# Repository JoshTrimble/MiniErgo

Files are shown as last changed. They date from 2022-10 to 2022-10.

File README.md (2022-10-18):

This design was inspired by the Gboards' GergoPlex. I wanted to take the base design and tweak it to be a smaller form factor, while maintaining the layout as much as possible. This board is driven by 2 Xiao Seeed Studio RP2040s and includes hot swappable sockets for Kailh Choc switches. The PCB is designed yp be double sided with the left side having the micro control placed upside down via standoffs.

One other thing to note; Because of the minimal footprint achieved, there might be a very slight overhang of the outer hot swap socket solder points and the edge of the board depending on the hot swap sockets used. There should be plenty of room for contact of the PCB tracks to the socket, and the excess can be sanded down to be flush with the PCB if desired. From my testing, you can't even notice. This design might be changed in future versions of the board. (P.S. Know that sanding PCBs can be hazardous. Please take procautions if you choose to sand anything attached to the board)

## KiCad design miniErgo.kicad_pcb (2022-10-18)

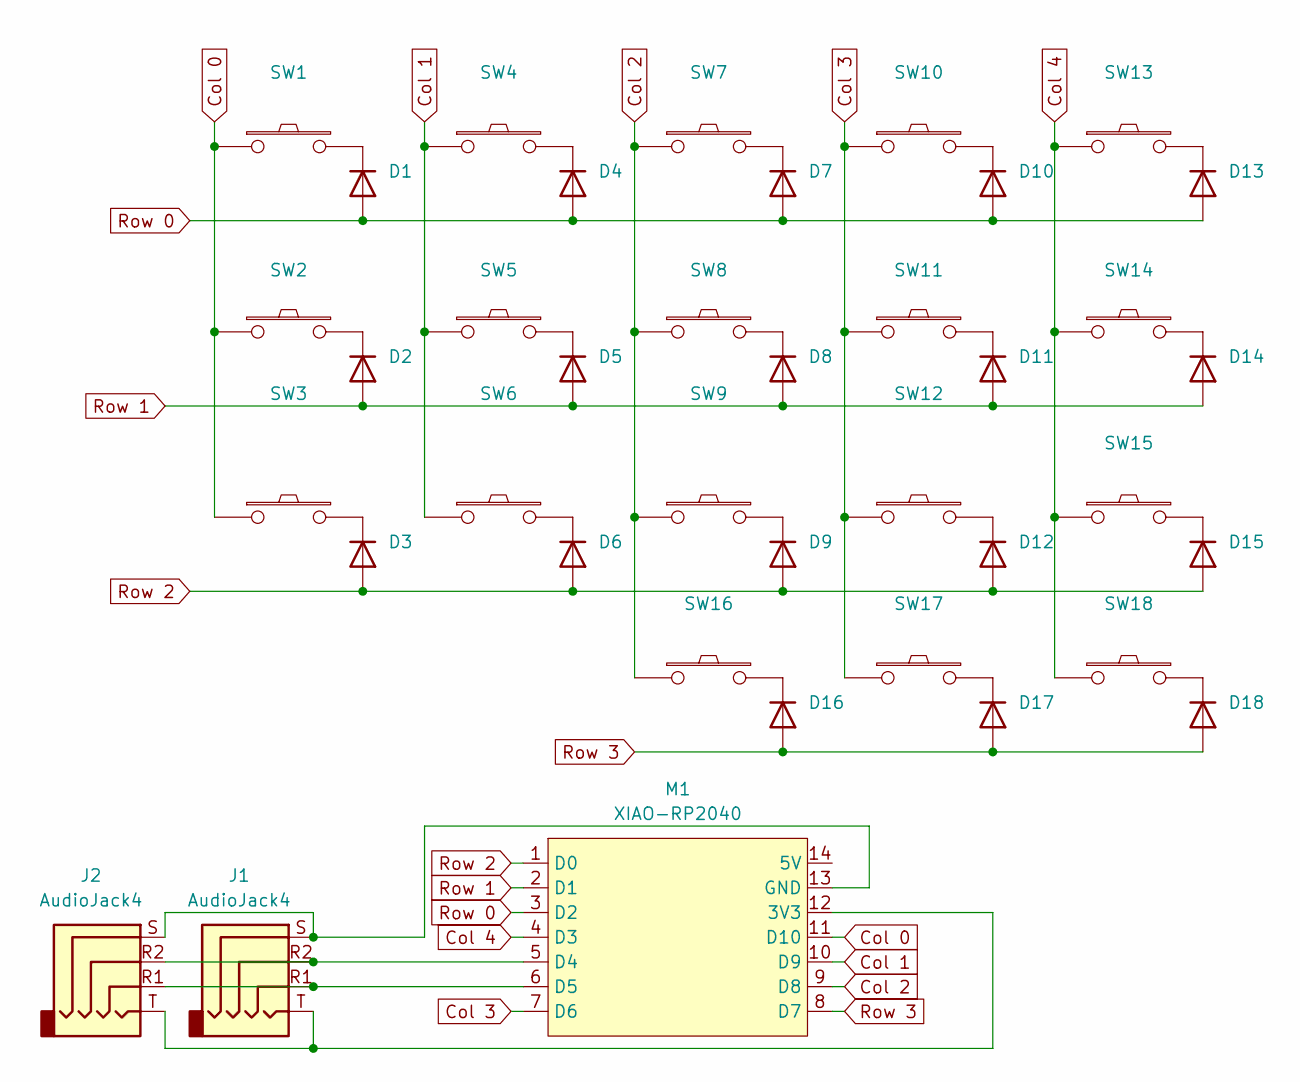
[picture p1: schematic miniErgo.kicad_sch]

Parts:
D1, D2, D3, D4, D5, D6, D7, D8, D9, D10, D11, D12, D13, D14, D15, D16, D17, D18: SOD-123F Double Sided
J1, J2: AudioJack4; TRRS-PJ-320A
M1: XIAO-RP2040
SW1, SW2, SW3, SW4, SW5, SW6, SW7, SW8, SW9, SW10, SW11, SW12, SW13, SW14, SW15, SW16, SW17, SW18: Kailh Choch HS Double Sided

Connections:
Col 0: M1.11 (D10), SW1.1, SW2.1, SW3.1
Col 1: M1.10 (D9), SW4.1, SW5.1, SW6.1
Col 2: M1.9 (D8), SW7.1, SW8.1, SW9.1, SW16.1
Col 3: M1.7 (D6), SW10.1, SW11.1, SW12.1, SW17.1
Col 4: M1.4 (D3), SW13.1, SW14.1, SW15.1, SW18.1
unnamed: D1.1 (K), SW1.2
unnamed: D2.1 (K), SW2.2
unnamed: D3.1 (K), SW3.2
unnamed: D4.1 (K), SW4.2
unnamed: D5.1 (K), SW5.2
unnamed: D6.1 (K), SW6.2
unnamed: D7.1 (K), SW7.2
unnamed: D8.1 (K), SW8.2
unnamed: D9.1 (K), SW9.2
unnamed: D10.1 (K), SW10.2
unnamed: D11.1 (K), SW11.2
unnamed: D12.1 (K), SW12.2
unnamed: D13.1 (K), SW13.2
unnamed: D14.1 (K), SW14.2
unnamed: D15.1 (K), SW15.2
unnamed: D16.1 (K), SW16.2
unnamed: D17.1 (K), SW17.2
unnamed: D18.1 (K), SW18.2
unnamed: J1.R1, J2.R1, M1.6 (D5)
unnamed: J1.R2, J2.R2, M1.5 (D4)
unnamed: J1.S, J2.S, M1.13 (GND)
unnamed: J1.T, J2.T, M1.12 (3V3)
Row 0: D1.2 (A), D4.2 (A), D7.2 (A), D10.2 (A), D13.2 (A), M1.3 (D2)
Row 1: D2.2 (A), D5.2 (A), D8.2 (A), D11.2 (A), D14.2 (A), M1.2 (D1)
Row 2: D3.2 (A), D6.2 (A), D9.2 (A), D12.2 (A), D15.2 (A), M1.1 (D0)
Row 3: D16.2 (A), D17.2 (A), D18.2 (A), M1.8 (D7)

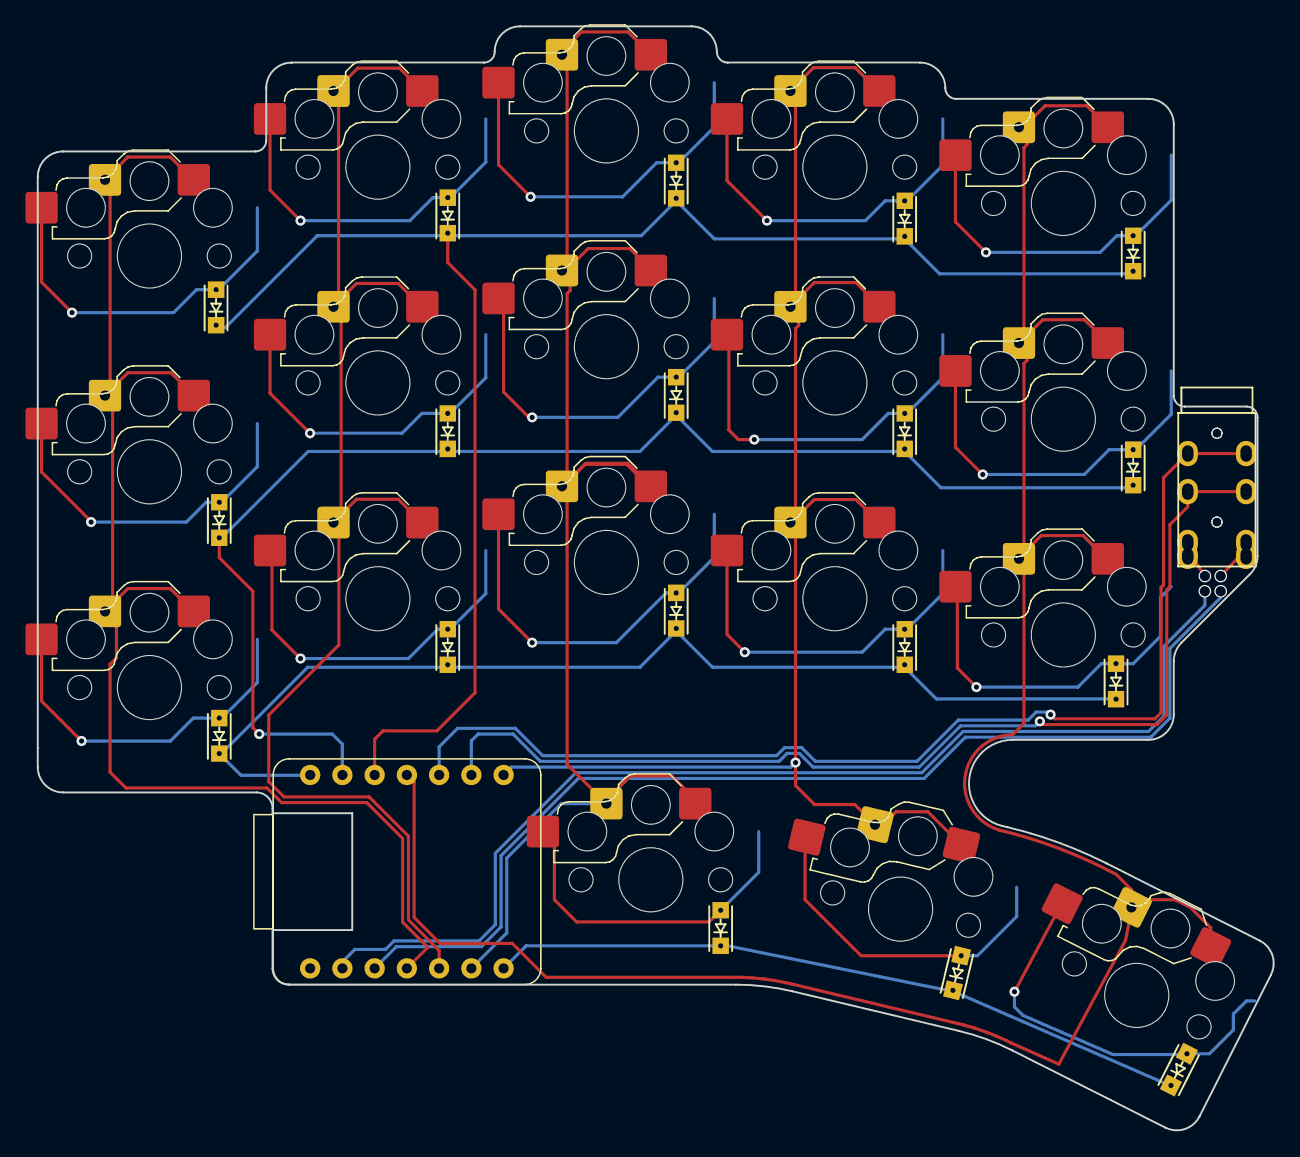
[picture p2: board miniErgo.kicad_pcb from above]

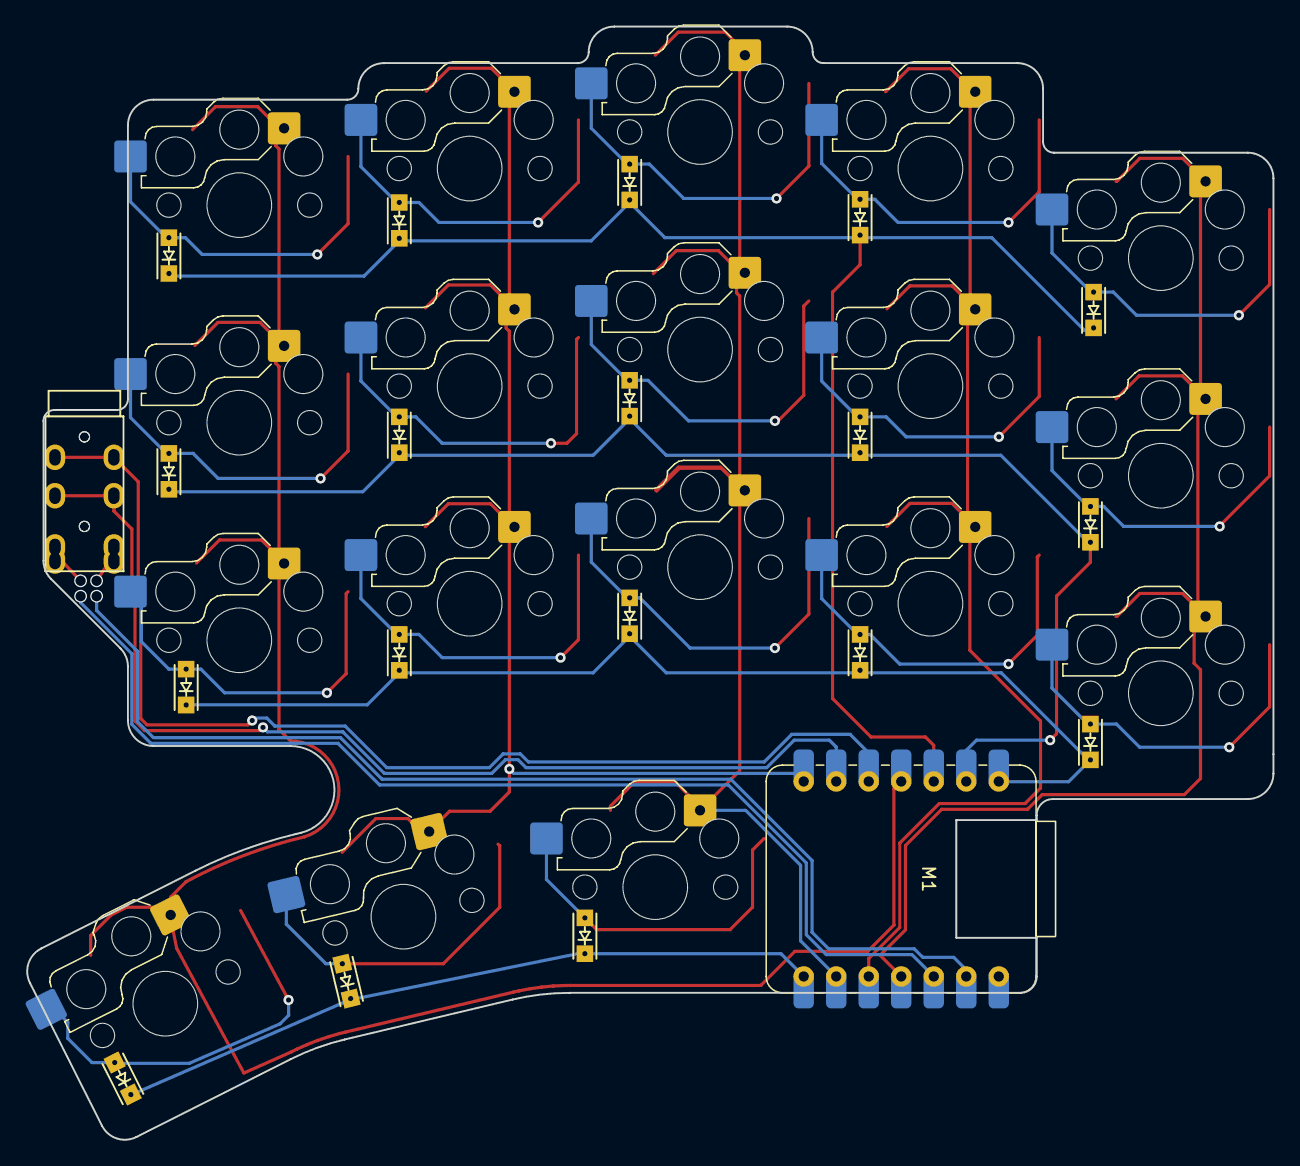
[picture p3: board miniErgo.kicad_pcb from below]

Board: 2 copper layers, 97.4 x 87.0 mm, 39 parts (20 on the bottom side), 31 nets.
